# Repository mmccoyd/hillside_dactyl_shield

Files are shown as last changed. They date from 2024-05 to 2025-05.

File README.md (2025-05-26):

# Hillside Dactyl Shield

| | |
|:--- |:---|
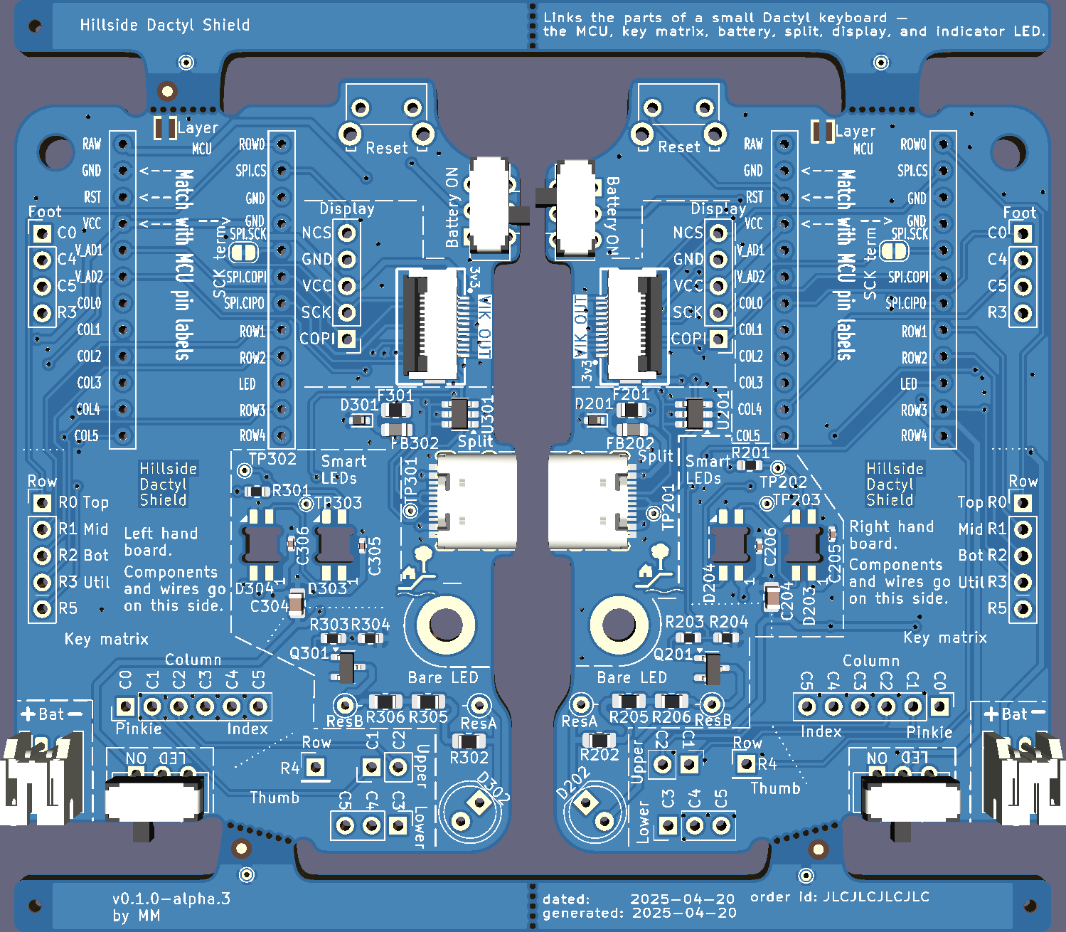
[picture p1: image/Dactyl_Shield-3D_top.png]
Render front
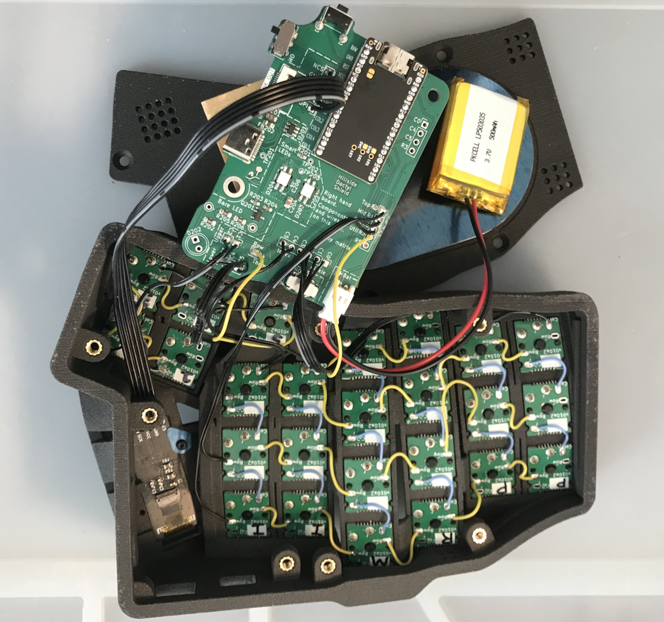
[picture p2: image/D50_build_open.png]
Use in Dactyl
|  |  |

These shields link the parts of a small Dactyl keyboard:
    the MCU, key matrix, battery, USB-C split, display, and underglow.
The shield fits below the index columns and display area of a
    choc Dactyl keyboard.
They should be useful for creating any modest sized Dactyl,
    but were designed for the
    [Hillside Dactyl 50](https://github.com/mmccoyd/hillside_dactyl_50).

## Feature levels

There are three main choice points in a shield cost vs features trade off.
See the wiki ordering page for costs.

- Wireless with key matrix, display, reset, power switch, and battery.
- Wired with ESD protection and PCBA parts placement.
- Vic link, LED underglow, and a decently clean emissions profile,
  using a four layer board with higher setup fees.

## What the shield provides

- A header to socket or solder a ProMicro footprint MCU.
- Key matrix headers for four or five rows, six columns,
   five thumbs, and three external switches.
- A battery switch and JST connector.
- A display header and Vik connector.
- Underglow or side indicator LEDs with power switch and cutoff solder jumpers.
- Extensive ESD protection on the USB-C split connection.
- Four or two layer construction options and PCBA construction.

## Designed as a four layer board, but also to work with two layers

Our highest priority was a cleanly working key matrix,
 followed by an informational display or LED.
Both with clean signal integrity and a properly low
  spurious emissions profile.
So the key matrix routing came first,
  followed by SPI routing for the display and LEDs.
Best practice for SPI seemed to be a four layer board,
    as SPI has fast edge transitions on typical keyboard processors.
Best practice is also to route high speed signals like SPI first,
    but I care more about the key matrix,
    and it seems to have high speed signal edge transitions as well.
So our layout is based on four layers with the inner layers as ground.
That gives the best signal integrity
  and hopefully a properly low emissions profile.
(The signal integrity in the wires flapping around inside the case
    is a different question.)

But four layer boards are more expensive in the small batches
    common with hobbyists.
So a two layer fabrication is also possible,
    as the MCU has direct outer layer ground traces to all ground pin uses.
But with two layers,
  the signal integrity for the matrix, LED, and display is unknown
  and an improper spurious emissions profile seems likely.

## Ordering board fabrication, parts, and building

[Releases](https://github.com/mmccoyd/hillside_dactyl_shield/releases)
    has the files for fabrication.

The [wiki](https://github.com/mmccoyd/hillside_dactyl_shield/wiki)
  has information on parts and ordering.
An example of its use in a keyboard can be found in the
    [Hillside Dactyl 50](https://github.com/mmccoyd/hillside_dactyl_50).

## Firmware

The [Hillside Dactyl 50](https://github.com/mmccoyd/hillside_dactyl_50),
    keyboard's ZMK and QMK firmware
    should be good starting points for creating similar Dactyls.

## Design notes

- The MCU goes face down.
  A dactyl is often not one's first ergo board
  and most ergo boards with a socketed MCU have it face down,
  so most of those building a dactyl likely have MCUs already pinned that way.
- The PCBA is configured for the Vik connector and battery and LED switches.
  It uses KiBot and is being tested using JLC's Economic PCBA.

## Other controller boards

Some other shields provide related abilities, including:

- A board with a built-in processor is
[BastardKB](https://bastardkb.com/)'s [Splinktegrated](https://bastardkb.com/product/splinktegrated-rp2040-controller/)
- The [Keebio Stampy](https://keeb.io/products/stampy-prototypes-rp2040-usb-c-controller-board-for-handwiring)
   RP2040 has three integrated switch footprints plus 26 pin breakouts.

## Images

There is also a STEP file in the GitHub action result files.

Front

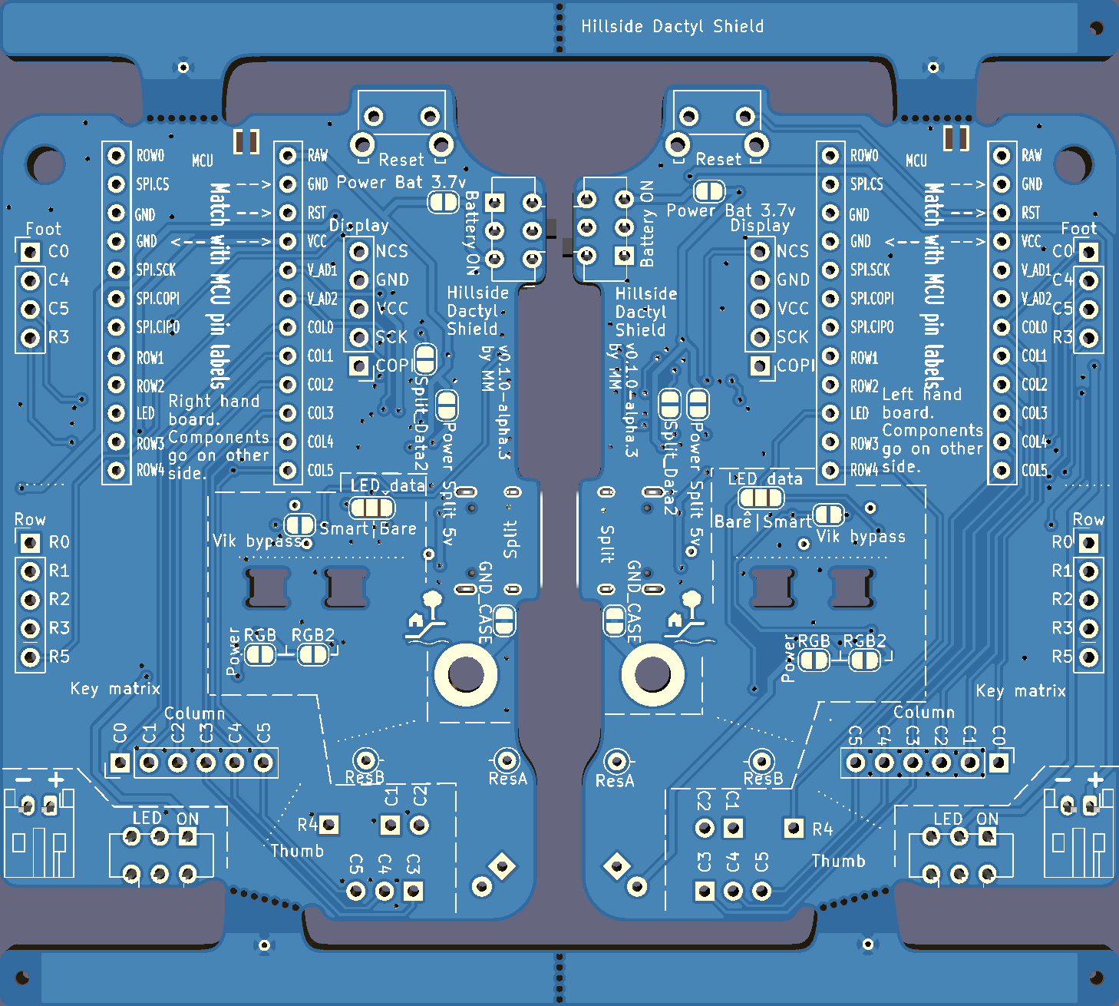
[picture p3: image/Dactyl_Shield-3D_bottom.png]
Back


Schematic side

Schematic

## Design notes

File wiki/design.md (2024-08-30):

# Design choices for use in a Dactyl

## No extra ESD protection in front of MCU board

The ProMicro footprint we're using doesn't break out the USB data pins.
And having an option of wired (2040) or wireless (Nice!Nano) is important.
It would nice as it would allow linking the two shield grounds,
  providing a clean path to earth ground for the split shield.
Right now the only path from split shield ground to earth ground is through
  the MCU's logic ground.
For now that will have to suffice.

## Four layer board

- As a non electrical engineer, routing SPI on mirrored boards
  is much simpler with four layers,
  to easily handle the return grounds under the forward paths.
- Getting a solid design comes before trying to do it in two layers.
- The downside is that four layers is more expensive, particularly in a panel,
  thought not proportionally as much more when already using PCBA.
  The PCB part of the cost does go up considerably,
  but from minimal to on par with the PCBA costs for small runs.
- A less capable two layer option is offered as a compromise.

## No extra RAW/Bat+ capacitors, due to USB in rush limit

USB in rush current limits restrict capacitance it sees to around 10 uF
  which the major 2040 boards have on RAW already.
We already violate USB by exposing the left and right 10 uF capacitors
  directly to the host, adding to it would make it worse.
For nice!nano and Bat+, they already have a 4.7 uF capacitor
  which should suffice.
Adding two power managers on the split line seems overkill,
  at least for a first version;
  though it would be one directional.
The downside is we are not boosting what is already there.

## MCU component side up

The MCU faces up so its onboard diagnostic LEDs are more visible.
Expanding the back panel USB slot a little sideways and upward seems likely effective.
Then the LEDs shine toward the debugger and don't hide below the USB cable.
A direct view of them is likely possible assuming a modest hole expansion.
An alternative of making holes in the breakout PCB and the bottom of the Dactyl case
  seems over worked and less visible.

It can still be use with if the MCU has socket pins already on it that would
  place the components face down,
  it just means the jumpers under the MCU must be soldered.

## Full SPI via header and a Vik "subset" connector

Allows a display or various tackpads with an to wire or a more advanced connection.
Sacrifices a possibly encoder_b pin for the MISO pin.
But no certified [Vik](https://github.com/sadekbaroudi/vik/tree/master)
  connector as we don't have enough pins to supply I2C and possibly two GPIO pins.

## SPI for Nice!Nano and 2040 ATmega32U4, but not ATmega32U4 ProMicro

High speed for Nice!Nano and ATmega32U4 are on different rows.
The 2040 supplants the ATmega32U4 anyway.

## External switches header, as columns 0, 4, 5 and rows 4 or 5

Sometimes foot switches are essential or can ease work on injured hands!
The columns skipped are the existing utility row keys plus just left of them
  which some people might add to the utility row based on their thumb cluster location.
An option of using row 4 or 5 gives a choice between full or partial:
  utility, external or number/macro keys sets.

## External switches header used, not TRRS jack, as space by board is tight

Plugging directly to the board would be nice, but threading an angled
  plug through the case wall and having space for it seems problematic.
A header provides a clean option for external switches,
  but that likely needs a larger or taller case.

## Split USB routes just D+, to simplify ESD

The stock firmware only needs one data line.
The downside is anything exotic needs to modify the split circuit,
  but exotic is rarer and some mods are reasonable.

## Split USB shield only connected to a mount hole pad

None of the MCU's offer a shield ground out of the keyboard.
So there is nowhere else to go except for the logic ground.

## Didn't use shift registers for more pins, as matrix scan is more important

To avoid the matrix scan sharing a bus with the display,
a SIPO shift register isn't used to create more pins.

## Ports 0 and 1 are used for input, despite slight power cost

Reworking for one port can wait for some dongle mode.
Reworking all those traces currently looks too painful.
Savings might be 1 or 7 uA?

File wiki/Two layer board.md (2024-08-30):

# Two layer board option

The four layer board construction,
  used for reliable SPI without spurious emissions,
  is expensive when done in small numbers.
However, a two layer option is available
  that supports the core bits of:
  power, ground, MCU, key matrix, and battery or split.
Building as a two layer board reduces the PCB cost
  from around $50 to around $12.
Adding PCBA still adds $37 or more to that,

## What the two layer option provides

The MCU has dedicated power and ground tracks,
  and the key matrix doesn't care so should still be fine.

Specifically:

- Power and ground have dedicated tracks on the outer (two layer)
  copper layers from the battery or the split to the MCU.
- That power and ground routing includes the
  split protection circuits and reset.
- The key matrix signals have dedicated out (column)
  and back (row) traces already.

Other things such as the LED, display, and whatever is connected to
  the Vic connector will not work with a two layer board.
This is because SPI with fast switching signal edges wants an unbroken
  return ground path right next to or under the signal path,
  and the top and bottom layers are not laid out to provided that.

## Ordering as a two layer board

On the initial PCB order screen,
  change the layer count from four to two
  after uploading the Gerber files.
JLC staff may query you as to whether you really meant to do that,
  as the uploaded files include all four layers.

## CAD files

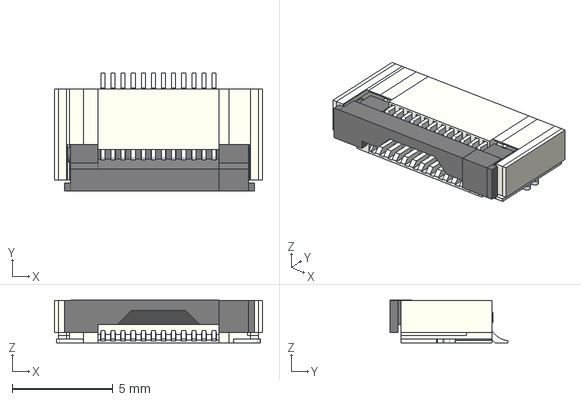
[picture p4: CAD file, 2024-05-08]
kicad/3dmodels/vik-connector-horizontal.stp
10.3 x 5.85 x 2.11 mm

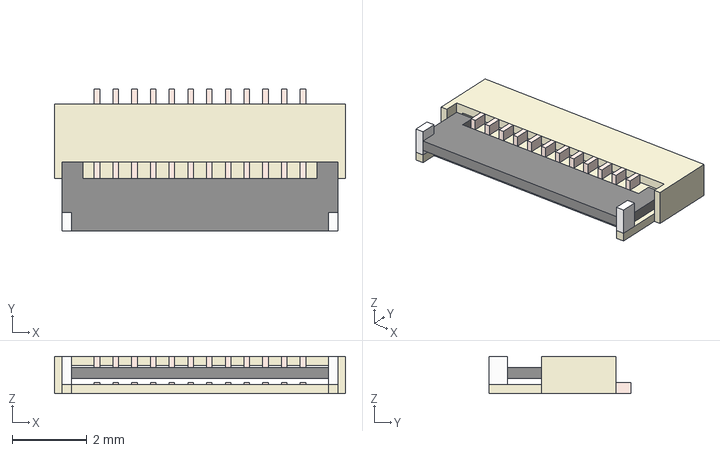
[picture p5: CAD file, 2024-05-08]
kicad/3dmodels/vik-connector-horizontal-mini.step
7.77 x 3.80 x 1.00 mm

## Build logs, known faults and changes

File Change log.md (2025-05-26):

# Change log

## v0.1.0-alpha.3: Fix soldering and resistors; easier hand wiring

Thou planned for just crucial fixes, this also reorganized the lower board half
    and keywell edge for clarity and easier keywell wiring.

### Changes

Breaking change (with respect to the body)

The alpha.3 shield mounts and fits within the alpha.2 body, but the
    smart LEDs and their power switch moved,
    so the holes in the bottom plate needed to move as well
    for the alpha.3 body.
Or some extra holes need to be cut into the alpha.2 bottom plate.

Fixes

-   Ground pins have manual thermal relief, not massive auto spoke counts.
-   LED configuration jumpers are all open, not cut-a-trace to open.
-   LED resistors have the intended values.
-   Bare LED can now reach its side wall hole, in a lengthened PCB.

Enhancements

-   The physical layout of the contacts for the key-matrix matches the layout
    of the thumb cluster and keywell edges they connect to.
    This makes it easier to see which wire connects where.
    At least for the Hillside Dactyl 50, which does have a typical layout.
-   Small test pads allow routing the LED data line to the second LED, to see
    if the first LED got fried by overzealous soldering. Or to bodge wire to
    the second LED with some solid core 26 AGW wire.
-   Reset and battery JST are included in PCBA.
-   CI uses KiBot JLCPCB template to create both four and two layer versions.

## v0.1.0-alpha.2: Left side and bare LED

The major addition is a left hand side. It is my daily board and works well.

### Known issues

-   Ground pins are very hard to solder because of far too many ground plane
    connections for a four layer board.
-   Opening solder jumpers requires cutting the trace,
    which is a pain and suspect on a four layer board.
-   The bare LED needs extra wire to reach outside the case.
-   Creating the release PCBA files required manually rotating the LED
    transistor.

### Changes

-   Panel of left and right shields.
-   Four layer, though can still be built as two layer.
-   Bare or smart LEDs.
-   Split ESD protection.

## v0.1.0-alpha.1: Initial. Not released

-   Initial. Not released.
-   Right hand only.
-   Smart LEDs.
-   Works fine, I've been using it for months.

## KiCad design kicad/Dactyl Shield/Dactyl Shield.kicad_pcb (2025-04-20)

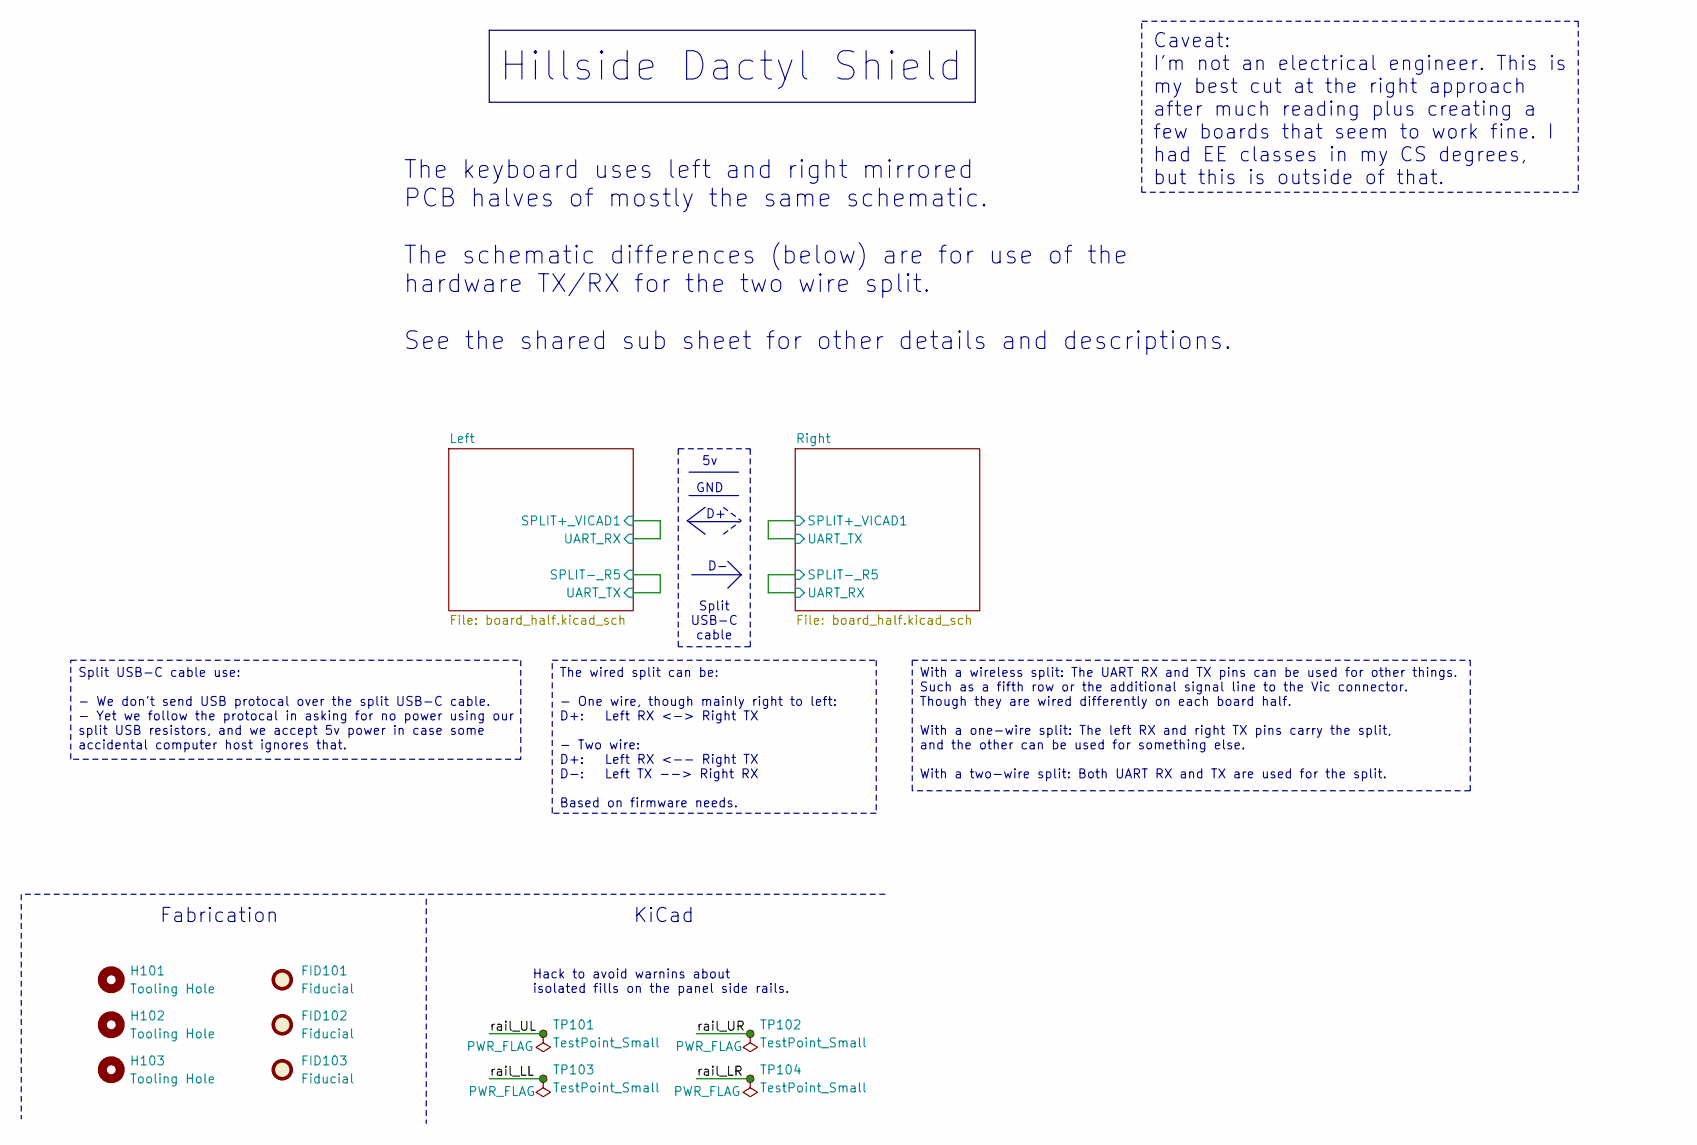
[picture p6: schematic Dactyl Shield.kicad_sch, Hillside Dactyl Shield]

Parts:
FID101, FID102, FID103: Fiducial; Fiducial_1mm_Mask2mm
H101, H102, H103: Tooling Hole; ToolingHole_1.152mm
TP101, TP102, TP103, TP104: TestPoint_Small; TestPoint_THTPad_D1.0mm_Drill0.5mm

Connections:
/rail_LL: TP103.1
/rail_LR: TP104.1
/rail_UL: TP101.1
/rail_UR: TP102.1

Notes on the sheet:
KiCad
Fabrication
${TITLE}
GND
The keyboard uses left and right mirrored PCB halves of mostly the same schematic. The schematic differences (below) are for use of the hardware TX/RX for the two wire split. See the shared sub sheet for other details and descriptions.
Hack to avoid warnins about isolated fills on the panel side rails.
Split USB-C cable use: - We don't send USB protocal over the split USB-C cable. - Yet we follow the protocal in asking for no power using our split USB resistors, and we accept 5v power in case some accidental computer host ignores that.
Caveat: I'm not an electrical engineer. This is my best cut at the right approach after much reading plus creating a few boards that seem to work fine. I had EE classes in my CS degrees, but this is outside of that.
With a wireless split: The UART RX and TX pins can be used for other things. Such as a fifth row or the additional signal line to the Vic connector. Though they are wired differently on each board half. With a one-wire split: The left RX and right TX pins carry the split, and the other can be used 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
The wired split can be: - One wire, though mainly right to left: D+: Left RX <-> Right TX - Two wire: D+: Left RX <-- Right TX D-: Left TX --> Right RX Based on firmware needs.
Split USB-C cable

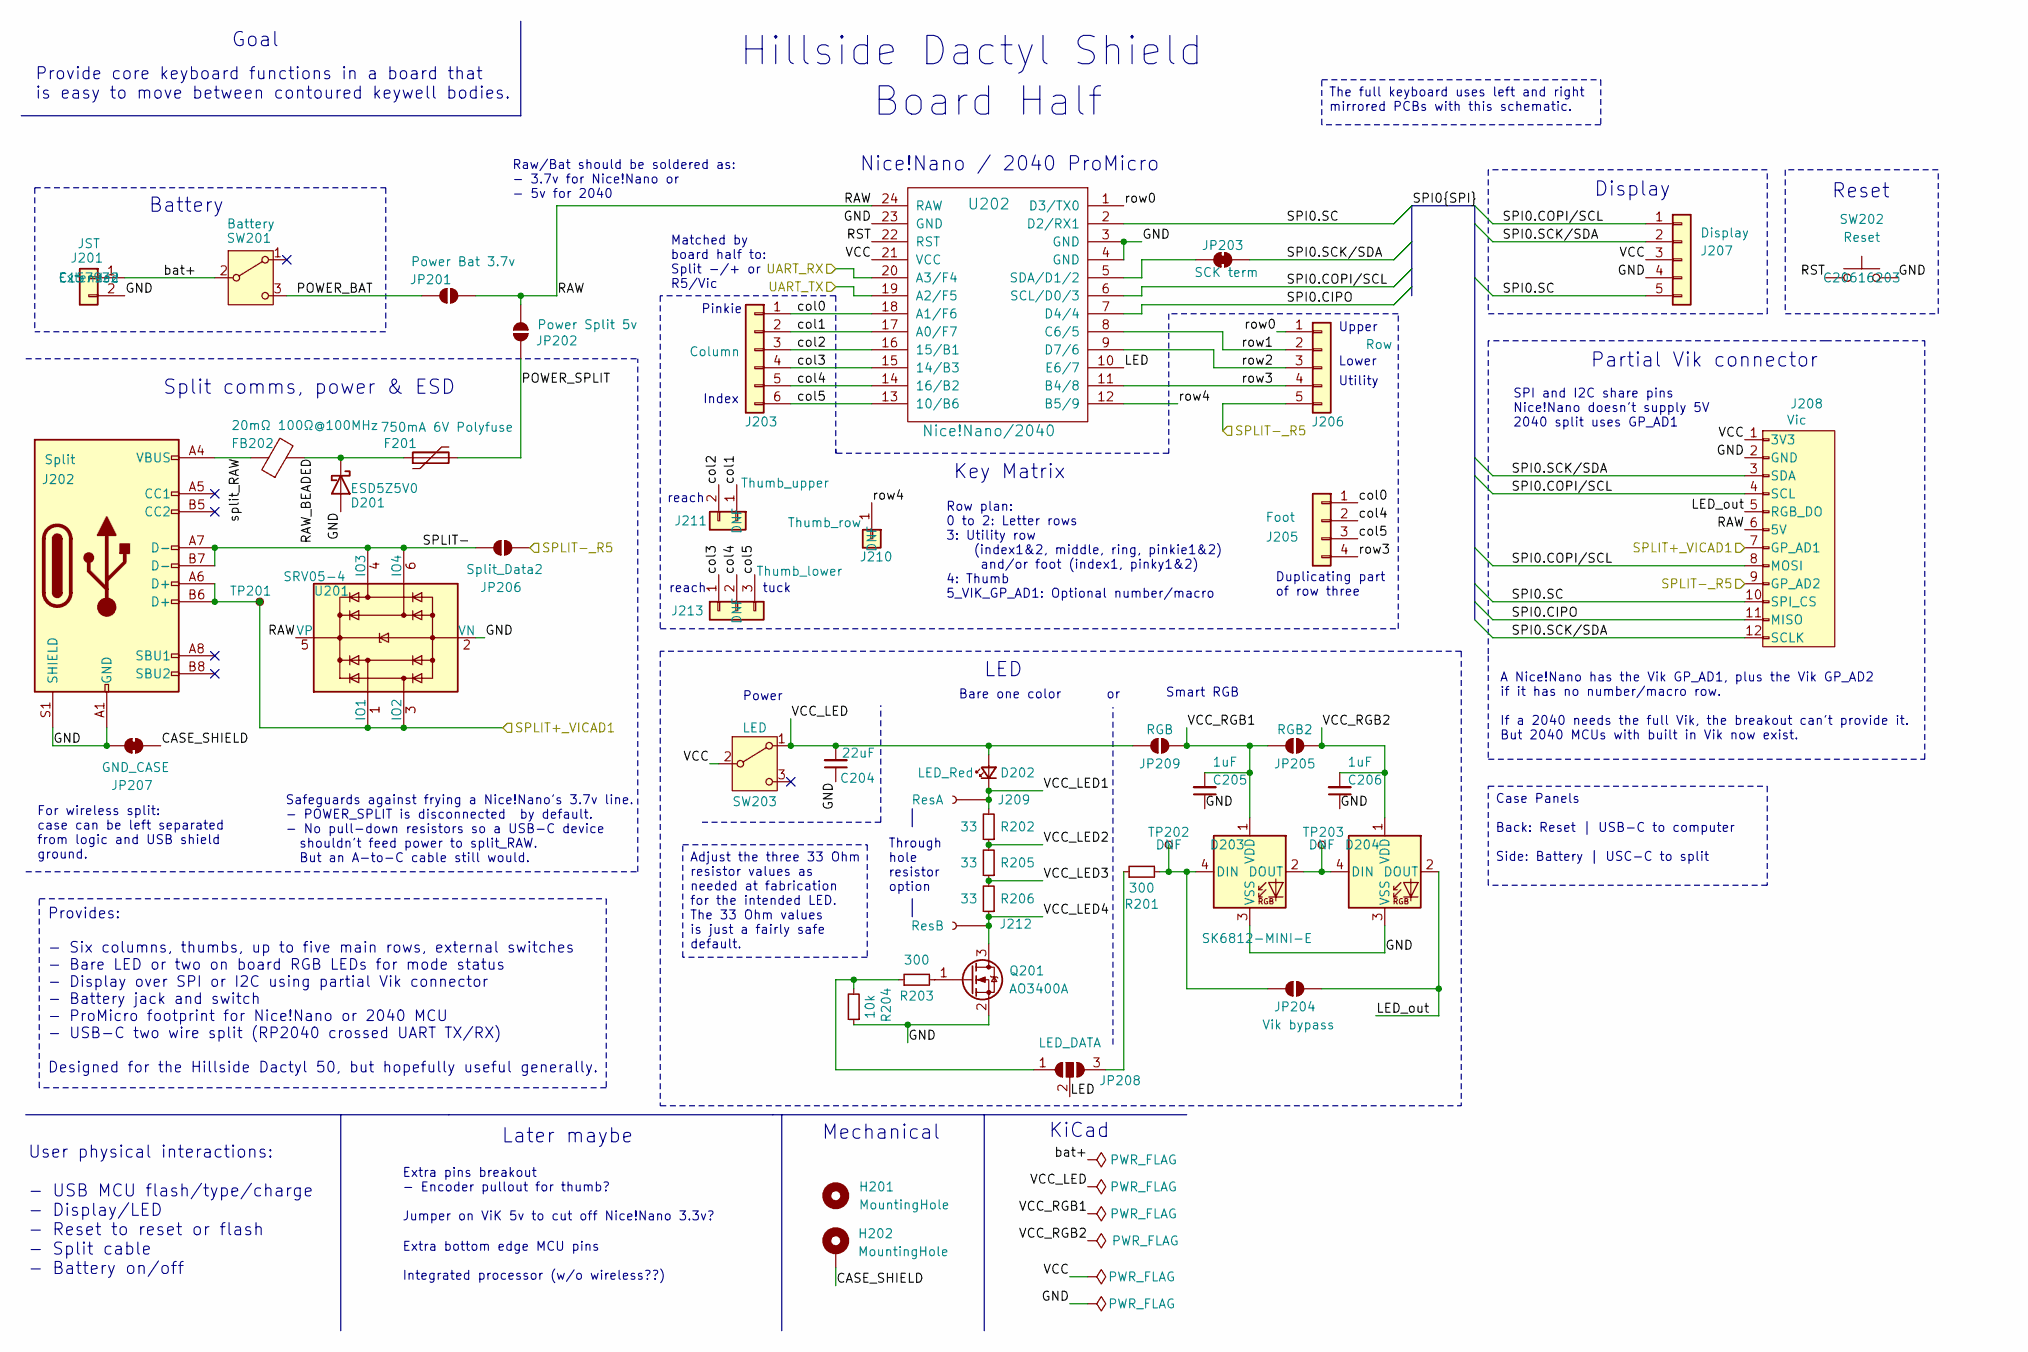
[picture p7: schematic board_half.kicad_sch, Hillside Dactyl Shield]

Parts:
C204: 22uF; C_0805_2012Metric; LCSC Part C45783
C205, C206: 1uF; C_0402_1005Metric; LCSC Part C52923
D201: ESD5Z5V0; D_SOD-523; JLC PCBA Type Extended
D202: LED_Red; LED_D5.0mm
D203, D204: SK6812-MINI-E; SK6812-MINI-E-Dog2_1S
F201: 750mA 6V Polyfuse; Fuse_0805_2012Metric; JLC PCBA Type Extended
FB202: 20mΩ 100Ω@100MHz; L_0805_2012Metric; JLC PCBA Type Extended
H201: MountingHole; MountingHole_3.2mm_M3_DIN965
H202: MountingHole; MountingHole_3.2mm_M3_DIN965_Pad
J201: JST; JST_PH_S2B-PH-K_1x02_P2.00mm_Horizontal; JLC PCBA Type Extended
J202: Split; USB_C_Receptacle_HRO_TYPE-C-31-M-12; JLC PCBA Type Extended
J203: Column; PinHeader_Columns
J205: Foot; PinHeader_External
J206: Row; PinHeader_Rows
J207: Display; PinHeader_Display
J208: Vic; vik-keyboard-connector-horizontal; JLC PCBA Type Extended
J209: ResA; Conn_Pin_D0.8mm
J210: Thumb_row; PinHeader_Thumb_row
J211: Thumb_upper; PinHeader_Thumb_upper
J212: ResB; Conn_Pin_D0.8mm
J213: Thumb_lower; PinHeader_Thumb_lower
JP201: Power Bat 3.7v; SolderJumper-2_P1.3mm_Open_RoundedPad1.0x1.5mm
JP202: Power Split 5v; SolderJumper-2_P1.3mm_Open_RoundedPad1.0x1.5mm
JP203: SCK term; SolderJumper-2_P1.3mm_Bridged_RoundedPad1.0x1.5mm
JP204: Vik bypass; SolderJumper-2_P1.3mm_Open_RoundedPad1.0x1.5mm
JP205: RGB2; SolderJumper-2_P1.3mm_Open_RoundedPad1.0x1.5mm
JP206: Split_Data2; SolderJumper-2_P1.3mm_Open_RoundedPad1.0x1.5mm
JP207: GND_CASE; SolderJumper-2_P1.3mm_Bridged_RoundedPad1.0x1.5mm
JP208: LED_DATA; SolderJumper-3_P1.3mm_Open_RoundedPad1.0x1.5mm
JP209: RGB; SolderJumper-2_P1.3mm_Open_RoundedPad1.0x1.5mm
Q201: AO3400A; SOT-23; JLC PCBA Type Econom
R201, R203: 300; R_0603_1608Metric; LCSC Part C23025
R202, R205, R206: 33; R_0805_2012Metric_Pad1.20x1.40mm_HandSolder; LCSC Part C17634
R204: 10k; R_0603_1608Metric; LCSC Part C25804
SW201: Battery; SW_SPDT_Battery; JLC PCBA Type Standard
SW202: Reset; SW_Tactile_SKHL_Angled; LCSC Part C20616203
SW203: LED; SW_SPDT_JS202011AQN_wider; JLC PCBA Type Standard
TP201, TP202, TP203: TestPoint_Small; TestPoint_THTPad_D1.0mm_Drill0.5mm
U201: SRV05-4; SOT-23-6; JLC PCBA Type Extended Prefer
U202: Nice!Nano/2040; ProMicro_v2_1S

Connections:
/Right/CASE_SHIELD: H202.1, JP207.2 (B)
/Right/GND: C204.1, C205.1, C206.1, D201.2 (A), D203.3 (VSS), D204.3 (VSS), J201.2, J202.A1 (GND), J202.A12 (GND), J202.B1 (GND), J202.B12 (GND), J202.S1 (SHIELD), J207.4, J208.2 (GND), JP207.1 (A), Q201.2 (S), R204.1, SW202.1, U201.2 (VN), U202.3 (GND), U202.4 (GND), U202.23 (GND)
/Right/LED: JP208.2 (C), U202.10 (E6/7)
/Right/LED_out: D204.2 (DOUT), J208.5 (RGB_DO), JP204.2 (B)
/Right/POWER_BAT: JP201.1 (A), SW201.3 (C)
/Right/POWER_SPLIT: F201.2, JP202.1 (A)
/Right/RAW: J208.6 (5V), JP201.2 (B), JP202.2 (B), U201.5 (VP), U202.24 (RAW)
/Right/RAW_BEADED: D201.1 (K), F201.1, FB202.2
/Right/RST: SW202.2, U202.22 (RST)
/Right/SPI0.CIPO: J208.11 (MISO), U202.7 (D4/4)
/Right/SPI0.COPI/SCL: J207.1, J208.4 (SCL), J208.8 (MOSI), U202.6 (SCL/D0/3)
/Right/SPI0.SC: J207.5, J208.10 (SPI_CS), U202.2 (D2/RX1)
/Right/SPI0.SCK/SDA: J207.2, J208.3 (SDA), J208.12 (SCLK), JP203.2 (B)
/Right/SPLIT+_VICAD1: J202.A6 (D+), J202.B6 (D+), J208.7 (GP_AD1), TP201.1, U201.1 (IO1), U201.3 (IO2), U202.19 (A2/F5)
/Right/SPLIT-: J202.A7 (D-), J202.B7 (D-), JP206.1 (A), U201.4 (IO3), U201.6 (IO4)
/Right/SPLIT-_R5: J206.5, J208.9 (GP_AD2), JP206.2 (B), U202.20 (A3/F4)
/Right/VCC: J207.3, J208.1 (3V3), SW203.2 (B), U202.21 (VCC)
/Right/VCC_LED: C204.2, D202.2 (A), JP209.1 (A), SW203.1 (A)
/Right/VCC_LED1: D202.1 (K), J209.1, R202.2
/Right/VCC_LED2: R202.1, R205.2
/Right/VCC_LED3: R205.1, R206.2
/Right/VCC_LED4: J212.1, Q201.3 (D), R206.1
/Right/VCC_RGB1: C205.2, D203.1 (VDD), JP205.1 (A), JP209.2 (B)
/Right/VCC_RGB2: C206.2, D204.1 (VDD), JP205.2 (B)
/Right/bat+: J201.1, SW201.2 (B)
/Right/col0: J203.1, J205.1, U202.18 (A1/F6)
/Right/col1: J203.2, J211.1, U202.17 (A0/F7)
/Right/col2: J203.3, J211.2, U202.16 (15/B1)
/Right/col3: J203.4, J213.1, U202.15 (14/B3)
/Right/col4: J203.5, J205.2, J213.2, U202.14 (16/B2)
/Right/col5: J203.6, J205.3, J213.3, U202.13 (10/B6)
/Right/row0: J206.1, U202.1 (D3/TX0)
/Right/row1: J206.2, U202.8 (C6/5)
/Right/row2: J206.3, U202.9 (D7/6)
/Right/row3: J205.4, J206.4, U202.11 (B4/8)
/Right/row4: J210.1, U202.12 (B5/9)
/Right/split_RAW: FB202.1, J202.A4 (VBUS), J202.A9 (VBUS), J202.B4 (VBUS), J202.B9 (VBUS)
unnamed: D203.4 (DIN), JP204.1 (A), R201.2, TP202.1
unnamed: D203.2 (DOUT), D204.4 (DIN), TP203.1
unnamed: JP203.1 (A), U202.5 (SDA/D1/2)
unnamed: JP208.1 (A), R203.1, R204.2
unnamed: JP208.3 (B), R201.1
unnamed: Q201.1 (G), R203.2

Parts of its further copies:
C304: 22uF; C_0805_2012Metric; LCSC Part C45783
C305, C306: 1uF; C_0402_1005Metric; LCSC Part C52923
D301: ESD5Z5V0; D_SOD-523; JLC PCBA Type Extended
D302: LED_Red; LED_D5.0mm
D303, D304: SK6812-MINI-E; SK6812-MINI-E-Dog2_1S
F301: 750mA 6V Polyfuse; Fuse_0805_2012Metric; JLC PCBA Type Extended
FB302: 20mΩ 100Ω@100MHz; L_0805_2012Metric; JLC PCBA Type Extended
H301: MountingHole; MountingHole_3.2mm_M3_DIN965
H302: MountingHole; MountingHole_3.2mm_M3_DIN965_Pad
J301: JST; JST_PH_S2B-PH-K_1x02_P2.00mm_Horizontal; JLC PCBA Type Extended
J302: Split; USB_C_Receptacle_HRO_TYPE-C-31-M-12; JLC PCBA Type Extended
J303: Column; PinHeader_Columns
J305: Foot; PinHeader_External
J306: Row; PinHeader_Rows
J307: Display; PinHeader_Display
J308: Vic; vik-keyboard-connector-horizontal; JLC PCBA Type Extended
J309: ResA; Conn_Pin_D0.8mm
J310: Thumb_row; PinHeader_Thumb_row
J311: Thumb_upper; PinHeader_Thumb_upper
J312: ResB; Conn_Pin_D0.8mm
J313: Thumb_lower; PinHeader_Thumb_lower
JP301: Power Bat 3.7v; SolderJumper-2_P1.3mm_Open_RoundedPad1.0x1.5mm
JP302: Power Split 5v; SolderJumper-2_P1.3mm_Open_RoundedPad1.0x1.5mm
JP303: SCK term; SolderJumper-2_P1.3mm_Bridged_RoundedPad1.0x1.5mm
JP304: Vik bypass; SolderJumper-2_P1.3mm_Open_RoundedPad1.0x1.5mm
JP305: RGB2; SolderJumper-2_P1.3mm_Open_RoundedPad1.0x1.5mm
JP306: Split_Data2; SolderJumper-2_P1.3mm_Open_RoundedPad1.0x1.5mm
JP307: GND_CASE; SolderJumper-2_P1.3mm_Bridged_RoundedPad1.0x1.5mm
JP309: RGB; SolderJumper-2_P1.3mm_Open_RoundedPad1.0x1.5mm
JP310: LED_DATA; SolderJumper-3_P1.3mm_Open_RoundedPad1.0x1.5mm
Q301: AO3400A; SOT-23; JLC PCBA Type Econom
R301, R303: 300; R_0603_1608Metric; LCSC Part C23025
R302, R305, R306: 33; R_0805_2012Metric_Pad1.20x1.40mm_HandSolder; LCSC Part C17634
R304: 10k; R_0603_1608Metric; LCSC Part C25804
SW301: Battery; SW_SPDT_Battery; JLC PCBA Type Standard
SW302: Reset; SW_Tactile_SKHL_Angled; LCSC Part C20616203
SW303: LED; SW_SPDT_JS202011AQN_wider; JLC PCBA Type Standard
TP301, TP302, TP303: TestPoint_Small; TestPoint_THTPad_D1.0mm_Drill0.5mm
U301: SRV05-4; SOT-23-6; JLC PCBA Type Extended Prefer
U302: Nice!Nano/2040; ProMicro_v2_1S

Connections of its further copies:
/Left/CASE_SHIELD: H302.1, JP307.2 (B)
/Left/GND: C304.1, C305.1, C306.1, D301.2 (A), D303.3 (VSS), D304.3 (VSS), J301.2, J302.A1 (GND), J302.A12 (GND), J302.B1 (GND), J302.B12 (GND), J302.S1 (SHIELD), J307.4, J308.2 (GND), JP307.1 (A), Q301.2 (S), R304.1, SW302.1, U301.2 (VN), U302.3 (GND), U302.4 (GND), U302.23 (GND)
/Left/LED: JP310.2 (C), U302.10 (E6/7)
/Left/LED_out: D304.2 (DOUT), J308.5 (RGB_DO), JP304.2 (B)
/Left/POWER_BAT: JP301.1 (A), SW301.3 (C)
/Left/POWER_SPLIT: F301.2, JP302.1 (A)
/Left/RAW: J308.6 (5V), JP301.2 (B), JP302.2 (B), U301.5 (VP), U302.24 (RAW)
/Left/RAW_BEADED: D301.1 (K), F301.1, FB302.2
/Left/RST: SW302.2, U302.22 (RST)
/Left/SPI0.CIPO: J308.11 (MISO), U302.7 (D4/4)
/Left/SPI0.COPI/SCL: J307.1, J308.4 (SCL), J308.8 (MOSI), U302.6 (SCL/D0/3)
/Left/SPI0.SC: J307.5, J308.10 (SPI_CS), U302.2 (D2/RX1)
/Left/SPI0.SCK/SDA: J307.2, J308.3 (SDA), J308.12 (SCLK), JP303.2 (B)
/Left/SPLIT+_VICAD1: J302.A6 (D+), J302.B6 (D+), J308.7 (GP_AD1), TP301.1, U301.1 (IO1), U301.3 (IO2), U302.20 (A3/F4)
/Left/SPLIT-: J302.A7 (D-), J302.B7 (D-), JP306.1 (A), U301.4 (IO3), U301.6 (IO4)
/Left/SPLIT-_R5: J306.5, J308.9 (GP_AD2), JP306.2 (B), U302.19 (A2/F5)
/Left/VCC: J307.3, J308.1 (3V3), SW303.2 (B), U302.21 (VCC)
/Left/VCC_LED: C304.2, D302.2 (A), JP309.1 (A), SW303.1 (A)
/Left/VCC_LED1: D302.1 (K), J309.1, R302.2
/Left/VCC_LED2: R302.1, R305.2
/Left/VCC_LED3: R305.1, R306.2
/Left/VCC_LED4: J312.1, Q301.3 (D), R306.1
/Left/VCC_RGB1: C305.2, D303.1 (VDD), JP305.1 (A), JP309.2 (B)
/Left/VCC_RGB2: C306.2, D304.1 (VDD), JP305.2 (B)
/Left/bat+: J301.1, SW301.2 (B)
/Left/col0: J303.1, J305.1, U302.18 (A1/F6)
/Left/col1: J303.2, J311.1, U302.17 (A0/F7)
/Left/col2: J303.3, J311.2, U302.16 (15/B1)
/Left/col3: J303.4, J313.1, U302.15 (14/B3)
/Left/col4: J303.5, J305.2, J313.2, U302.14 (16/B2)
/Left/col5: J303.6, J305.3, J313.3, U302.13 (10/B6)
/Left/row0: J306.1, U302.1 (D3/TX0)
/Left/row1: J306.2, U302.8 (C6/5)
/Left/row2: J306.3, U302.9 (D7/6)
/Left/row3: J305.4, J306.4, U302.11 (B4/8)
/Left/row4: J310.1, U302.12 (B5/9)
/Left/split_RAW: FB302.1, J302.A4 (VBUS), J302.A9 (VBUS), J302.B4 (VBUS), J302.B9 (VBUS)
unnamed: D303.4 (DIN), JP304.1 (A), R301.2, TP302.1
unnamed: D303.2 (DOUT), D304.4 (DIN), TP303.1
unnamed: JP303.1 (A), U302.5 (SDA/D1/2)
unnamed: JP310.1 (A), R303.1, R304.2
unnamed: JP310.3 (B), R301.1
unnamed: Q301.1 (G), R303.2

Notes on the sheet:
Extra pins breakout - Encoder pullout for thumb? Jumper on ViK 5v to cut off Nice!Nano 3.3v?
SPI and I2C share pins Nice!Nano doesn't supply 5V 2040 split uses GP_AD1
Duplicating part of row three
Matched by board half to: Split -/+ or R5/Vic
Upper
Board Half
Index
For wireless split: case can be left separated from logic and USB shield ground.
Through hole resistor option
Utility
Battery
Key Matrix
Bare one color
tuck
Pinkie
Row plan: 0 to 2: Letter rows 3: Utility row (index1&2, middle, ring, pinkie1&2) and/or foot (index1, pinky1&2) 4: Thumb 5_VIK_GP_AD1: Optional number/macro
Safeguards against frying a Nice!Nano's 3.7v line. - POWER_SPLIT is disconnected by default. - No pull-down resistors so a USB-C device shouldn't feed power to split_RAW. But an A-to-C cable still would.
Smart RGB
Lower
Display
KiCad
${TITLE}
Provide core keyboard functions in a board that is easy to move between contoured keywell bodies.
User physical interactions: - USB MCU flash/type/charge - Display/LED - Reset to reset or flash - Split cable - Battery on/off
reach
Goal
Mechanical
Nice!Nano / 2040 ProMicro
Power
Partial Vik connector
LED
Raw/Bat should be soldered as: - 3.7v for Nice!Nano or - 5v for 2040
Later maybe
Reset
Extra bottom edge MCU pins Integrated processor (w/o wireless??)
A Nice!Nano has the Vik GP_AD1, plus the Vik GP_AD2 if it has no number/macro row. If a 2040 needs the full Vik, the breakout can't provide it. But 2040 MCUs with built in Vik now exist.
The full keyboard uses left and right mirrored PCBs with this schematic.
Adjust the three 33 Ohm resistor values as needed at fabrication for the intended LED. The 33 Ohm values is just a fairly safe default.
Provides: - Six columns, thumbs, up to five main rows, external switches - Bare LED or two on board RGB LEDs for mode status - Display over SPI or I2C using partial Vik connector - Battery jack and switch - ProMicro footprint for Nice!Nano or 2040 MCU - USB-C two wire split (RP2040 crossed UART TX/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
Case Panels Back: Reset | USB-C to computer Side: Battery | USC-C to split

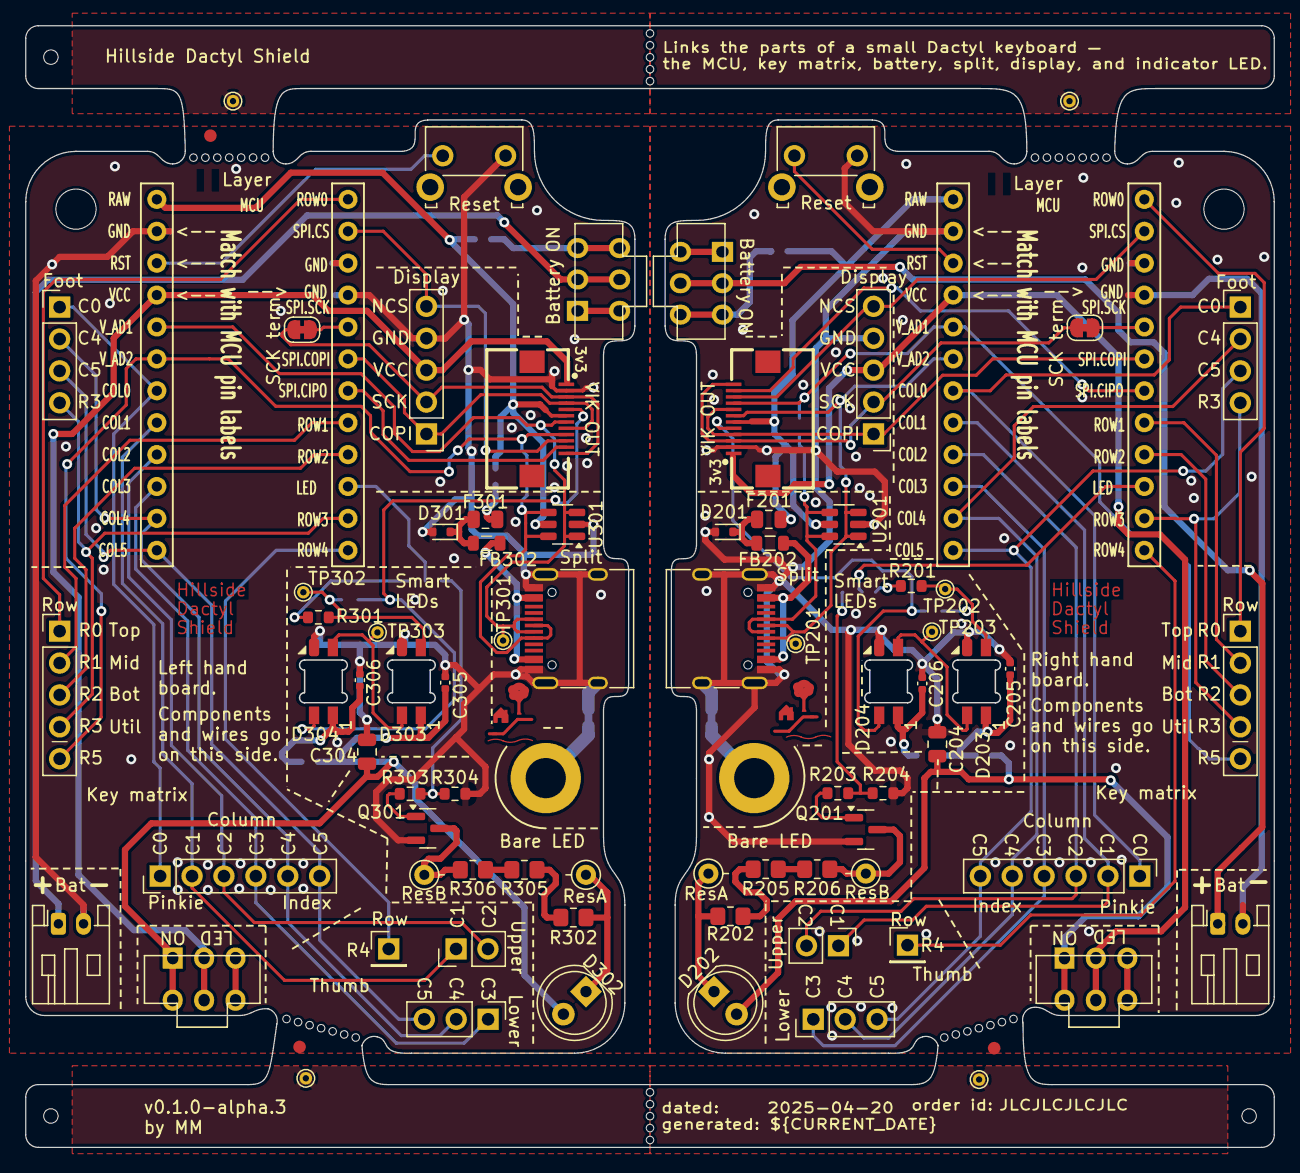
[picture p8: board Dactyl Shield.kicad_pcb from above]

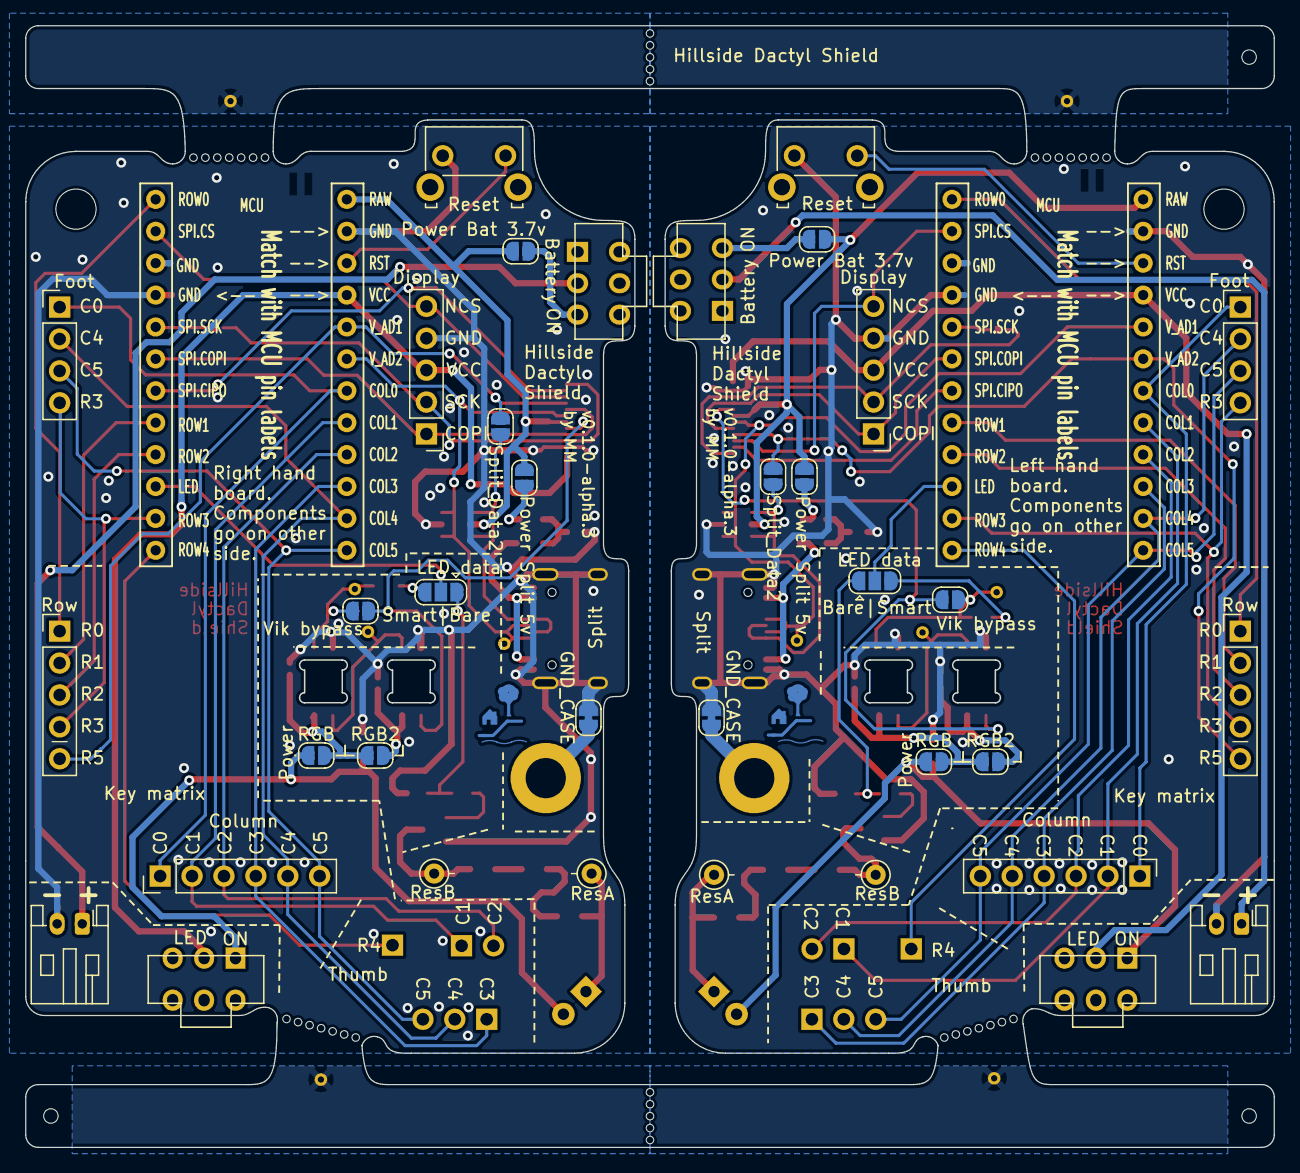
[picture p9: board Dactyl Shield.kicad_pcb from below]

Board: 4 copper layers, 99.4 x 89.3 mm, 104 parts (16 on the bottom side), 86 nets.

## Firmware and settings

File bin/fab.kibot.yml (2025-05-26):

# Create fabrication files for JLCPCB using KiBot

# See: https://kibot.readthedocs.io/en/master/configuration/outputs.html

kibot:
  version: 1

globals:
  field_lcsc_part: LCSC Part # So JLCPCB template knows where part numbers are
  output: '%f_rev_%r-%i%I%v.%x'  # Include board revision number

import:
  # Internal JLCPCB template does most of the work

  - file: JLCPCB
    definitions:
      _KIBOT_IMPORT_ID: '_four_layer'
      _KIBOT_IMPORT_DIR: 'JLC_four_layer'
      _KIBOT_POS_DNF_FILTER: remove_extra
      _KIBOT_POS_ONLY_SMD: false
      _KIBOT_POS_PRE_TRANSFORM: fix_rotation
      _KIBOT_PLOT_FOOTPRINT_VALUES: true

  - file: JLCPCB
    definitions:
      _KIBOT_IMPORT_ID: '_two_layer'
      _KIBOT_IMPORT_DIR: 'JLC_two_layer'
      _KIBOT_POS_DNF_FILTER: remove_extra
      _KIBOT_POS_ONLY_SMD: false
      _KIBOT_POS_PRE_TRANSFORM: fix_rotation
      _KIBOT_PLOT_FOOTPRINT_VALUES: true
      _KIBOT_GERBER_LAYERS:
        - F.Cu
        - B.Cu
        - F.SilkS
        - B.SilkS
        - F.Mask
        - B.Mask
        - Edge.Cuts

preflight:
  erc: true
  check_zone_fills: true
  drc: true


filters:

- name: fix_rotation
  comment: 'Adjust rotation for JLC'
  type: rot_footprint
  negative_bottom: false
  mirror_bottom: true
  rotations_and_offsets:
    - field: _field_lcsc_part # Vic  - need in toward pins / center of panel
      regex: 'C2906115'
      offset_y: -0.5  # minus is in direction of the pins

    - field: _field_lcsc_part # SRV05 ESD: need 90° counter clockwise
      regex: 'C20615829'
      angle: -90

    - field: _field_lcsc_part # USB-C
      regex: 'C165948'
      offset_y: -1.4 # minus is in direction of the pins

- name: remove_extra
  comment: 'Keep only those with a LCSC Part number'
  type: generic
  include_only:
    - column: LCSC Part
      regex: "^C\\d+"

outputs:

  - name: Bill_of_Materials
    comment: BoM
    type: bom
    dir: doc

  - name: I_Bill_of_Materials
    comment: I_BoM
    type: ibom
    dir: doc

  - name: Render_Top
    comment: Render with PCBA components
    type: render_3d
    dir: doc
    options:
      dnf_filter:  remove_extra
      auto_crop: true
      clip_silk_on_via_annulus: false
      height: 1500
      width: 1500

  - name: Render_Bottom
    comment: Render with PCBA components
    type: render_3d
    dir: doc
    options:
      dnf_filter:  remove_extra
      auto_crop: true
      clip_silk_on_via_annulus: false
      view: 'bottom'
      height: 1500
      width: 1500

  - name: Schematic
    comment: Schematic export
    type: svg_sch_print
    dir: doc
    options:
      background_color: true

  - name: Step_3D_file
    comment: Step file export
    type: step
    dir: step

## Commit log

2024-03-01 feat: kicad initial project
    [Dactyl MCU Breakout.kicad_pcb, Dactyl MCU Breakout.kicad_sch]
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2024-05-08 feat: schema and board: matrix display led split
    [Dactyl MCU Breakout.kicad_pcb, Dactyl MCU Breakout.kicad_sch]
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2024-05-08 feat; temp delete all traces
    [Dactyl MCU Breakout.kicad_pcb]
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2024-05-08 feat: jumpered MCU, Vik, shift register, external
    [Dactyl MCU Breakout.kicad_pcb, Dactyl MCU Breakout.kicad_sch]
2024-05-08 refactor: half sheet schematic, for non-reversable
    [Dactyl MCU Breakout.kicad_sch]
2024-05-08 refactor: board half sub sheet, some net labels
    [board_side.kicad_sch]
2024-05-08 feat: bus SPI0, mum/2040 split steal form Vik
    [Dactyl MCU Breakout.kicad_sch, board_side.kicad_sch]
2024-05-08 refactor(pcb): prep: delete all traces, vias
    [Dactyl MCU Breakout.kicad_pcb]
2024-05-08 feat: add column to thumb, shift split to Vik AD1
    [Dactyl MCU Breakout.kicad_sch, board_half.kicad_sch]
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2024-05-08 feat(3D models): vik models
    [vik-connector-horizontal-mini.step, vik-connector-horizontal.stp]
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2024-05-08 feat(pcb): 3D models lowers all headers
    [Dactyl MCU Breakout.kicad_pcb]
2024-05-08 feat(pcb): mount point further from bat swittch
    [Dactyl MCU Breakout.kicad_pcb]
2024-05-08 feat: area reserved for TRRS. base plate notch
    [Dactyl MCU Breakout.kicad_pcb, Dactyl MCU Breakout.kicad_sch, board_half.kicad_sch]
2024-05-08 feat: left: reset and batt, right: two inserts
    [Dactyl MCU Breakout.kicad_pcb, board_half.kicad_sch]
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2024-05-08 feat: split usb sticks out more
    [Dactyl MCU Breakout.kicad_pcb]
2024-05-08 feat(schematic): use Config field DNF for non PCBA
    [board_half.kicad_sch]
2024-05-08 feat(PCB): get rid of example keys
    [Dactyl MCU Breakout.kicad_pcb]
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2024-05-08 build(KiBot): compress, report unconnected
    build(KiBot): fix short name use
    build(KiBot): fix output dirs
    build(KiBot): fix log ls
    build(KiBot): better logging and dir cd
    build(KiBot): fix paths
    build(KiBot): ignore unconnected
    build(KiBot): try dcr filter
    build(KiBot): try dcr filter
    build(KiBot): disable to get error
    build(KiBot): disable to get error
    build(KiBot): drill filse
    [fab.kibot.yml]
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2024-05-08 feat: rename LCSC part column
    [Dactyl MCU Breakout.kicad_pcb, board_half.kicad_sch]
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2024-05-14 doc: schema doc cleanup
    [Dactyl MCU Breakout.kicad_pcb, board_half.kicad_sch]
2024-05-24 feat: rails floating around pcb, with tool holes
    [Dactyl MCU Breakout.kicad_pcb]
2024-07-03 feat: panel rails, back silk on footprints
    [Dactyl MCU Breakout.kicad_pcb, board_half.kicad_sch]
2024-07-03 feat: vic connector faces in for curve radious
    [Dactyl MCU Breakout.kicad_pcb]
2024-07-03 feat: corner cutout for bottom plate support
    [Dactyl MCU Breakout.kicad_pcb]
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2024-07-03 feat: Handedness jumper, better case corner notch
    - Move panel details to separate project
    - Remove Col 0 from thumb header
    - Add handedness solder jumper and diode
    - Add corner notch for case bottom mount
    - Clean up silks and wiring
    [Dactyl MCU Breakout.kicad_pcb, Dactyl MCU Breakout.kicad_sch, board_half.kicad_sch]
2024-07-03 feat: panel project holding left and right boards
    [MCU Breakout Panel.kicad_pcb, MCU Breakout Panel.kicad_sch]
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2024-07-03 feat: ESD protection. Tidy up before mirroring
    [Dactyl MCU Breakout.kicad_pcb, board_half.kicad_sch]
2024-07-04 chore: update KiCad to 8.0.3
    [Dactyl MCU Breakout.kicad_pcb]
2024-07-04 feat(Kibot): fix Vic offset. Show footprint silks.
    [fab.kibot.yml]
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2024-07-04 feat: simplify battery JST to one sided
    [Dactyl MCU Breakout.kicad_pcb, board_half.kicad_sch]
2024-07-04 feat(PCBA): add parts numbers for ESD and diode
    [Dactyl MCU Breakout.kicad_pcb, board_half.kicad_sch]
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2024-07-04 feat(KiBot): fix Vic offset. add ESD rotate
    [fab.kibot.yml]
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2024-07-04 feat(KiBot): fix Vic offset
    [fab.kibot.yml]
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2024-07-04 feat(foot): fix silk on LED switch
2024-07-04 feat: fix silk on LED switch
    [Dactyl MCU Breakout.kicad_pcb]
2024-07-05 feat: four layer PCB, inners GND. Reconnect GNDs.
    [Dactyl MCU Breakout.kicad_pcb]
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2024-07-05 feat: shrink width so two fit in 100 mm wide panel
    [Dactyl MCU Breakout.kicad_pcb]
2024-07-15 feat(pcb): 0.1 mm grid for components and edges
    [Dactyl MCU Breakout.kicad_pcb]
2024-07-16 feat(pcb): set grid origin for panel mirror point
    [Dactyl MCU Breakout.kicad_pcb]
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2024-07-16 feat(pcb): mirror flipped
    [Dactyl MCU Breakout.kicad_pcb]
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2024-07-17 feat(scheme): fix some mislabels
    [Dactyl MCU Breakout.kicad_pcb]
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2024-07-18 feat(pcb): put breaks for panel at whole mm's
    [Dactyl MCU Breakout.kicad_pcb]
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2024-07-18 reorg(panel): remove panel project. Using one is cleaner
    [MCU Breakout Panel.kicad_pcb, MCU Breakout Panel.kicad_sch]
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2024-07-26 feat(PCB): straight edge cut on side by case wall
    [Dactyl MCU Breakout.kicad_pcb]
2024-07-26 feat(PCB): higher side mount hole for case bend
    [Dactyl MCU Breakout.kicad_pcb]
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2024-08-16 feat: larger close capacitors, top/bottom fill
    - Solder jumpers for split or battery to reduce the risk of attaching both.
    - Wider 0.5 mm tracks for power.
    - LED isolation capacitors have smaller loop distance and higher uF within size.
    - USB shield ground routed to mount hole pad, as no better place to go.
    - Ground fill for top and bottom layers, as well as the middle layer ones.
    - Artwork in copper of a small house on a wooded hillside next to a stream.
    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
    [Dactyl MCU Breakout.kicad_pcb, Dactyl MCU Breakout.kicad_sch, board_half.kicad_sch]
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2024-08-30 feat(pcb): outer layers fill GND, route key paths
    [Dactyl MCU Breakout.kicad_pcb]
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2024-10-03 feat: usb shield to ground, jumper to case shield
    [Dactyl Shield.kicad_pcb, board_half.kicad_sch]
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2024-12-31 feat: swap power and reset location on right board
    [Dactyl Shield.kicad_pcb]
2025-01-15 feat: route ground traces, fix mirror positions
    [Dactyl Shield.kicad_pcb, board_half.kicad_sch]
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2025-01-15 feat(KiBot): attempt to rotate LED transistor fail
    [fab.kibot.yml]
2025-01-15 feat: reset on back, power slides to right
    [Dactyl Shield.kicad_pcb, Dactyl Shield.kicad_sch, board_half.kicad_sch]
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2025-04-13 feat: cleanup error warnings
    [board_half.kicad_sch]
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2025-04-14 feat: key headers match body grid layout (rough)
    - Right hand only and just a rought sketch so far
    [Dactyl Shield.kicad_pcb, board_half.kicad_sch]
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2025-04-20 fix: resistors have correct PCBA part id
    [Dactyl Shield.kicad_pcb, board_half.kicad_sch]
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2025-04-20 feat(pcba): add reset switch
    project exclusions exclude four way junction
    [Dactyl Shield.kicad_pcb, board_half.kicad_sch]
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2025-05-02 ci: fix: show component values (labels) on silk
    [fab.kibot.yml]
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
